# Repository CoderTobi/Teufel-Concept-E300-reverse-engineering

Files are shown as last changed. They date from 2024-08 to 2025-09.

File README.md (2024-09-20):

# Teufel Concept E300 Reverse Engineering
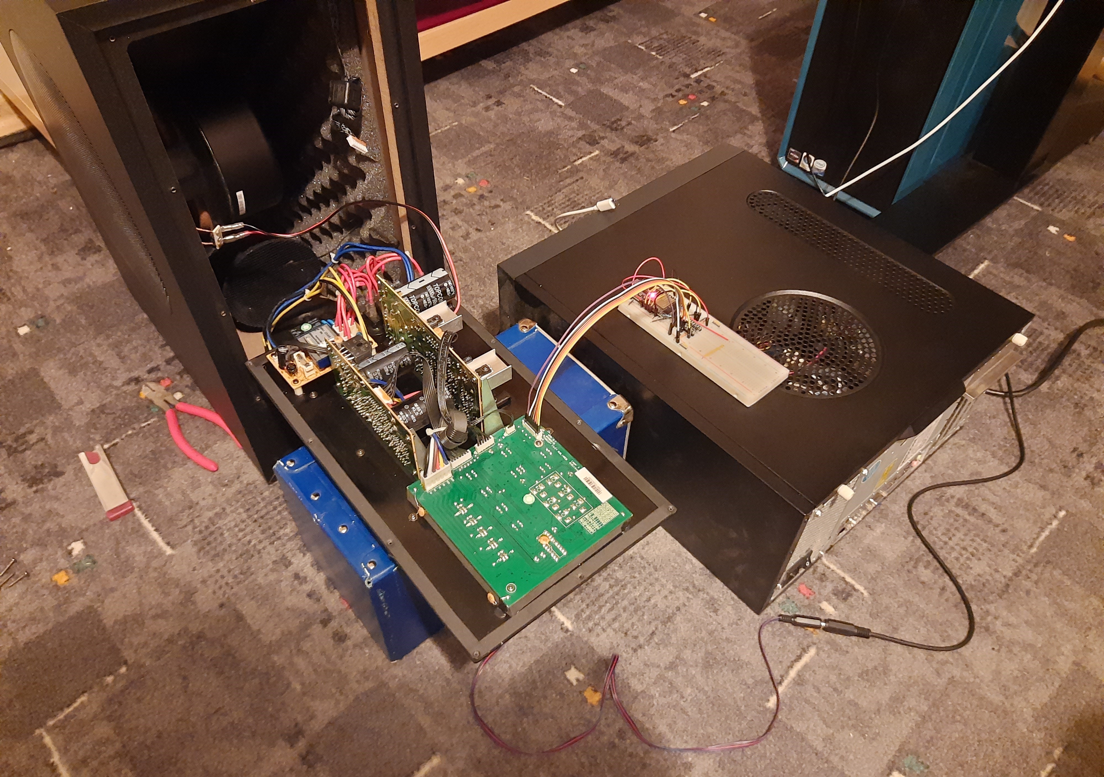
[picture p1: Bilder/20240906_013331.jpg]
Cover Bild

Dieses Repository enthält alle Dateien von meinem Reverse Engineering Projekt meines 5.1 Surround Sound Systems.
Beim System handelt es sich um einen Concept E3 der Marke Teufel.
Die Erkenntnisse aus diesem Projekt können jedoch sehr wahrscheinlich auf andere Systeme der Marke Teufel übertragen werden, solange sie aus einer ähnlichen Zeit stammen (ca. 2010).

## Warnung!
Das Testen und Sammeln von Informationen erforderte das Arbeiten am Subwoofer während er mit Netzspannung versorgt wurde. Sowohl die 230V Wechselspannung als auch die 50V Gleichspannung am Amplifier können potentiell tödlich sein. Wenn du nicht weist, was du tust und keine Erfahrung mit Elektronik hast, dann solltest du nicht mit solchen Spannungen arbeiten. Ich bin nicht verantwortlich solltest du dich bei einem ähnlichen Projekt oder dergleichen verletzen.

## For English speaking people
This repository contains all files for a hobby project of mine where I reverse engineered a 5.1 surround sound system manufactured by the German company Teufel. Since I am German and I don't think my system was sold outside of Germany I wrote all the documentation in German too. If my assumption was wrong or you're just interested in the project it's self, you can open an issue and request a translation... or just use a translator.

## Caution!
This project involved working on the subwoofer while it was connected to mains voltage and the components exposed. If you don't know what you are doing you should not do a project like this. I am not responsible if you hurt yourself or anything like that because you did know what you were doing.

## Hinweis
Dieses Projekt ist noch nicht abgeschlossen und unfertig.

## Motivation
Ich hab mich schon immer für Elektronik und deren Zusammenspiel mit Informatik interessiert. Dementsprechend hatte ich schon immer bei jedem Gerät das Interesse es zu zerlegen und herauszufinden wie es funktioniert.
Der Vorbesitzer meines Systems verkaufte mir damals das System, da es ihn störte jedes mal an den Subwoofer hin laufen zu müssen, um in aus dem Standby zu wecken. In Foren fand ich weitere Personen die es stört, dass das System jedes mal in den Standby zurückkehrt, wenn man die Stromversorgung unterbricht.
Da ich gefühlt jedes Gerät zu irgendeinem Zeitpunkt zerlege, war auch mein Subwoofer keine Ausnahme. Beim Zerlegen und Bewundern der Platine sprang mir eine Sache direkt ins Auge. Die Leitungen, die von der Gehäusefront mit dem Standbyknopf und den Lautstärkereglern zurück zum Mainboard führten, waren die Beschriftungen `SDA` und `SCL` aufgedruckt. Diese deuteten auf einen I2C Bus hin. Da Sowohl der Atmel Atmega328p (Arduino nano) als auch der ESP32 einen bzw. zwei I2C Busse haben entstand die Idee meinen Subwoofer Smart zu machen, sprich ihn nicht nur per WLAN wecken, sondern auch die Lautstärke einstellen zu können.
2024 entstand dann während meiner Semesterferien dieses Projekt aus der ursprünglichen Idee.

## Setup
Falls irgendjemand ebenfalls noch ein altes System der Firma Teufel hat und es auch in Home Assistant integrieren will habe ich ein paar Hilfestellungen dafür aufgeschrieben. Siehe: [Setup](Docs/Setup/README.md)

## Dokumentation meines Systems
Ich habe versucht alle meine Erkenntnisse über mein System in ein paar Markdown Dokumenten zusammenzufassen. Siehe: [Concept E3](Docs/Concept_E300/README.md)

## Reverse Engineering
Für die Leute, die sich vielleicht überlegen ein ähnliches Projekt durchzuführen oder einfach nur interessiert sind, wie ich dabei vorgegangen bin, habe ich ein bisschen Prosa verfasst. Siehe hier: [Reverse Engineering](Docs/Reverse_Engineering/README.md)

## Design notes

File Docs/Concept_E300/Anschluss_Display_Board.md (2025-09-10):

# Anschluss Display Board
Das Display Board auf welchem sich die Regler für die Lautstärke und den Bass, als auch der Knopf für den Standby befinden, ist über einen 7-Pin JST-HX Stecker mit dem Mainboard verbunden. Genau diesen Anschluss verwende ich, um meinen Subwoofer über HomeAssistant zu steuern.

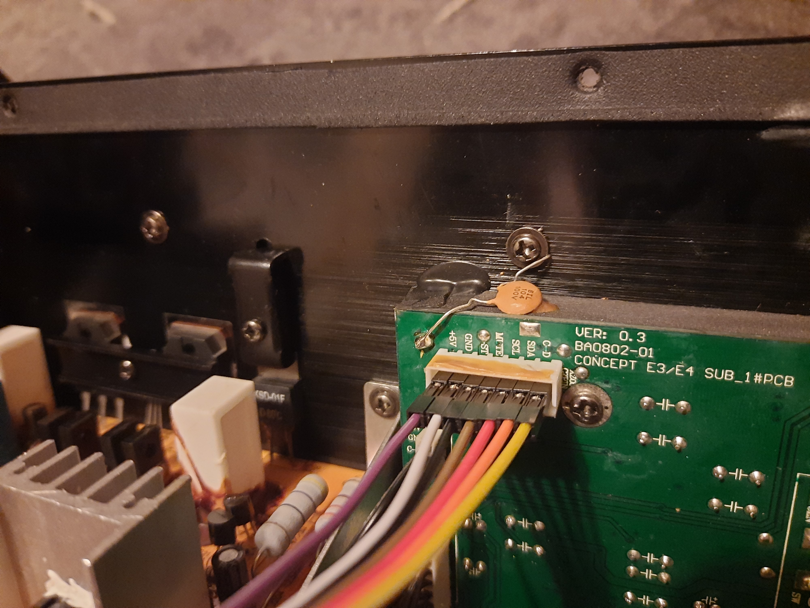
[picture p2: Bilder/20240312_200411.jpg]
Bild vom Anschluss am Mainboard


| Label | Bedeutung | high | low |
| --- | --- | --- | --- |
| +5V | | | |
| GND | | | |
| ST | Standby | Sleep | Work |
| MUTE/Control | | AMP an | AMP aus |
| SCL | | | |
| SDA | | | |
| C-D | Vielleicht Channel Disconnect | kein Audio | Audio erkannt |

## ST-Pin
Der ST-Pin ist für das Schalten des Standby Relais zuständig. Dieses unterbricht die Spannungsversorgung zum großen Trafo am Boden des Subwoofers. Wenn ST auf `HIGH` ist schaltet das Relais nicht durch. Wenn ST auf `LOW` ist schaltet das Relais durch und die beiden Amps werden über den großen Trafo mit Spannung versorgt.

Da ST am Standby Netzteil mit der Basis eines 2N5401 PNP Transistors verbunden ist, welcher dann wiederum über einen 2N5551 NPN Transistor das Relais schält, muss ST zuverlässig auf GND geschaltet werden, um das Relais zu steuern.
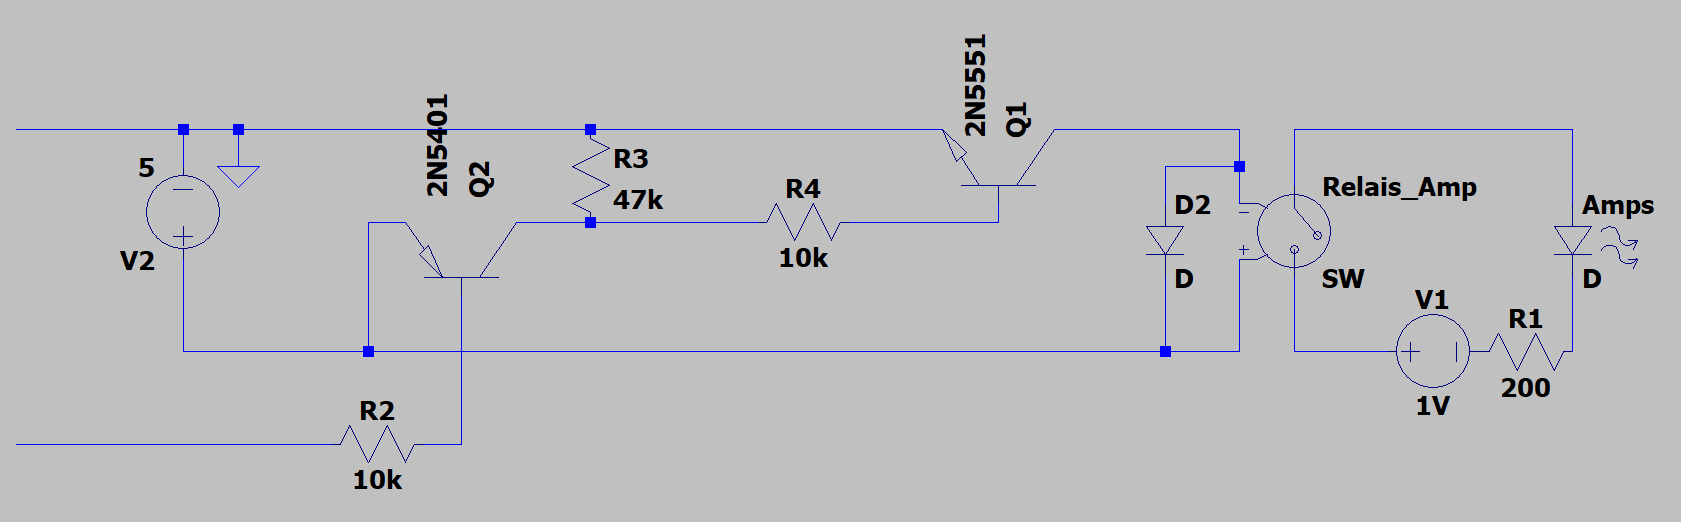
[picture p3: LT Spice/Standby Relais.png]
Schaltplan Standby Relais

Es reicht nicht ST direkt an einen ESP32 zu hängen und den GPIO-PIN auf `LOW` zu setzen. Dementsprechend funktionieren auch simple I2C Logic Level Shifter nicht, da diese nur das `LOW` Signal des Mikrocontrollers durchschalten und zusätzlich noch einen 10k Ohm Pull Up hinzufügt.

## MUTE / Control
Nach dem ST auf `LOW` geschaltet wurde, muss der MUTE Pin auf `HIGH` geschaltet werden. Das Display Board von Teufel wartet hier erst noch ca. 3 Sekunden bevor der Pin auf 5V geschaltet wird. Das Signal wird vom Mainboard glaub ich einfach an die beiden Amps durchgereicht. Beim Amp des Subwoofers wird MUTE als Control bezeichnet.

Wenn MUTE über einen GPIO Pin eines ESP32 auf 3,3V geschaltet wird, schält das Relais des Subwoofer Amps und entmutet in. Der AMP der Satelliten Lautsprecher ist dann jedoch unbrauchbar leise. Dies ist auch der Fall, wenn MUTE über einen 10k Ohm Pull Up auf 5V geschaltet wird. 
Dementsprechend funktionieren I2C Logic Level Shifter auch nicht, da diese nur einen 10K Ohm Pull Ip auf 5V verwenden.

MUTE wird nur korrekt als `HIGH` erkannt, wenn der Pin über einen 1k Ohm Pull Up oder direkt mit 5V verbunden wird. Siehe [Issue #3](https://github.com/CoderTobi/Teufel-Concept-E300-reverse-engineering/issues/3).

Mit meinem Multimeter habe ich versucht den Stromfluss auf MUTE bei `HIGH` zu messen, der Strom war jedoch zu gering für mein Messgerät.

## SCL und SDA
SCL und SDA werden für die Übertragung der Lautstärke über das I2C Protokoll verwendet. Siehe: [Protokoll](Protokoll.md)

## C-D
Ich weiß nicht genau wofür `C-D` steht. Aber es scheint vom Display Board mit wahrscheinlich 10k Ohm auf 5V hochgezogen zu werden. Wenn aber das Display Board getrennt wird, dann liegen an `C-D` entweder 4,8V oder 0V an, je nach dem, ob gerade Musik abgespielt wird. Es wird dabei jedoch nur Audio beachtet, dass über die beiden vorderen Lautsprecher (FR und FL) abgespielt werden soll.

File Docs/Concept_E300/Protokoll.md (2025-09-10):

# Protokoll
Das Display Board kommuniziert mit dem Restlichen System via I2C. 
Siehe für weitere Informationen auch [Aufbau](Aufbau.md) und [Anschluss Display Board](Anschluss_Display_Board.md).

## Aufbau eines Pakets
TODO

## Einschalten
Beim Einschalten wird zuerst `ST` auf `low` gesetzt.
Dann ca. 2,5 Sekunden gewartet.
Anschließend werden über ``I2C`` Daten ausgetauscht. (TODO)
Dann nach 0,35 Sekunden `MUTE`auf `high` gesetzt.

> [!CAUTION]
> `MUTE` darf erst auf `high` gesetzt werden, nachdem `ST` ca. 3 Sekunden auf `low` war.

> [!WARNING]
> Sollten die AMPs via I2C keine Informationen über die gewünschte Lautstärke erhalten, kann es zu unerwartetem Verhalten kommen.
> Auf Grund eines Wackelkontakts hatte ich beispielsweise schon den Fall, dass einer der Satelliten Lautsprecher extrem laut war.

## Ausschalten
Zuerst werden Daten via ``I2C`` ausgetauscht. (TODO)
Dann `MUTE` wird auf `low` gesetzt.
10 Mikro Sekunden später dann `ST` auf `high`.

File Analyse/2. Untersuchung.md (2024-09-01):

Herausfinden wofür der Pin CD ist:

- Pin hatte immer die gleiche Spannung von 4,4V (VCC)
- Spannung wurde vom Display Board geliefert
- Kein Unterschied ob auf High oder Low
- Verändert sich auch nich, wenn man eine Quelle anschließt oder was abspielt

Herausfinden wie sich der Sub verhält wenn der Bass-Regler auf max is und ich den Lautstärke Regler von min auf max dreh

- 2 neue Captures unter "Volume Slider"
- Verhält sich wie erwartet außer bei 100% Volume
- In der Excel Datei Diagramme erstellt
- Entscheidung: Abknicken beim Bass nicht implementieren, sondern einfach nur ein Schutz, dass die Dämpfung nicht negativ sein kann

Spannungen nachprüfen

- überall VCC (4,4V)
Stromstärke messen (Wichtig auf Pin Mute und ST weil die glaub direkt an das Relay gehen)
- Strom an ST und MUTE zu gering zum messen
- Strom gesamt max 30mA

CD in meiner Firmware implementieren

- Pin einfach immer auf HIGH gesetzt

Vielleicht einen Test mit meinem ESP machen

- Anpassungen an Firmware bezüglich Volume bei 100% und Bass Veränderungen

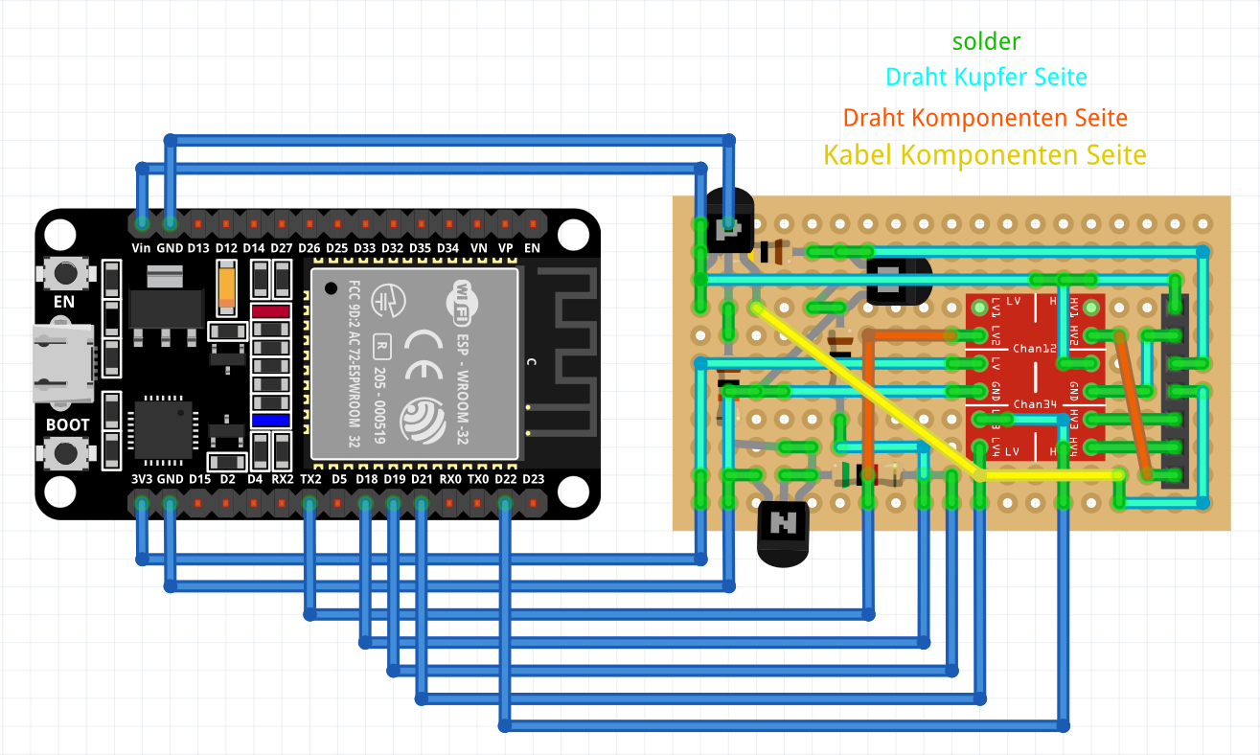
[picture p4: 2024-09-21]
Fritzing/Perfboard.png

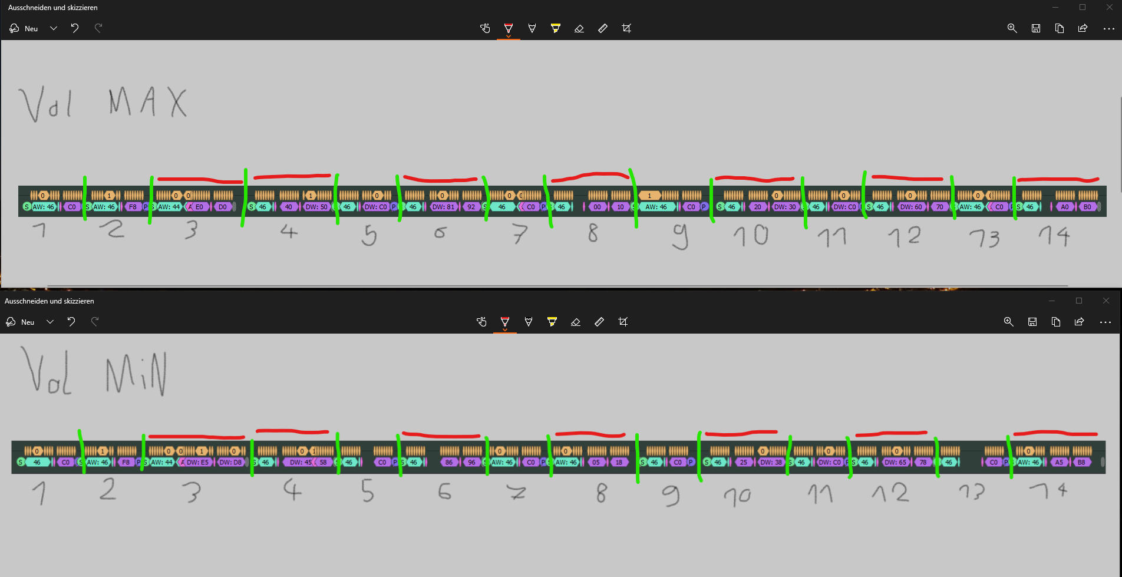
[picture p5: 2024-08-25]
Analyse/Paket Analyse Volume.png

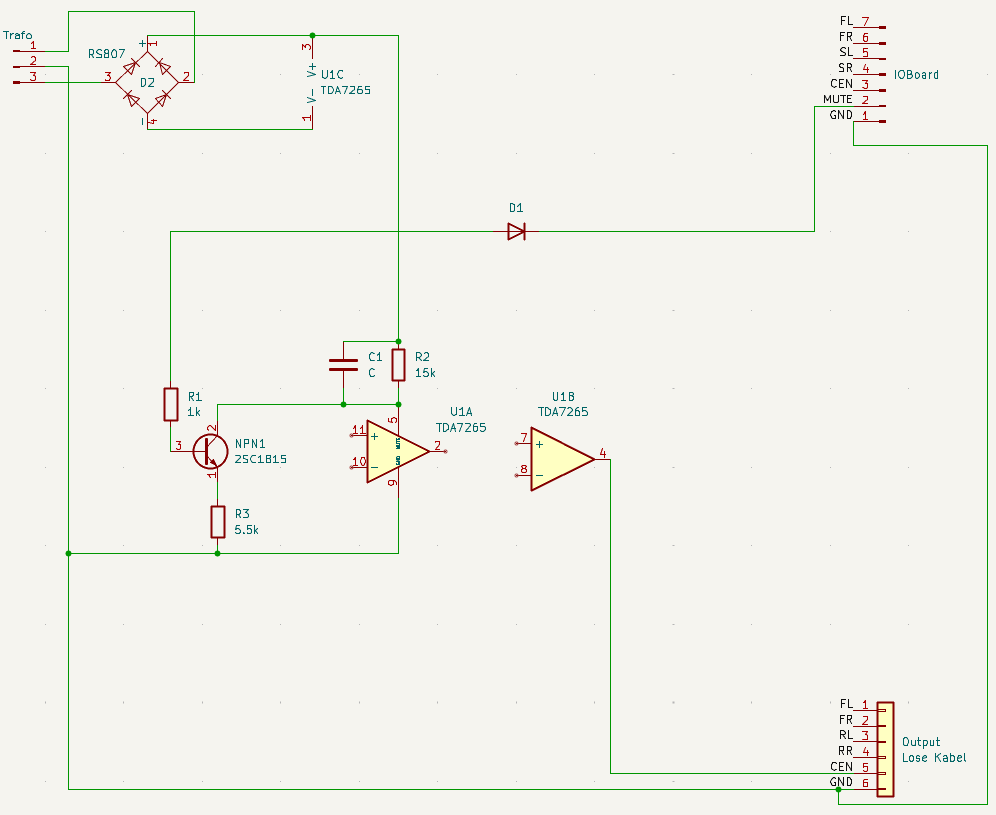
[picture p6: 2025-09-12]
KiCad/SatelliteAMP.png

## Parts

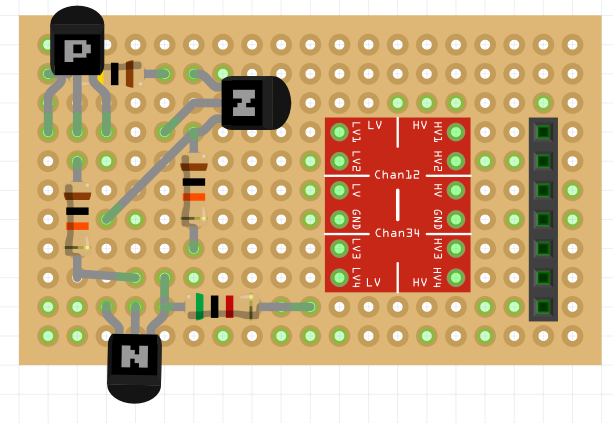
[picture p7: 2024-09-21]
Fritzing/Perfboard-Components_only.png

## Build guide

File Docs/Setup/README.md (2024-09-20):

# Setup
In diesem Bereich ist beschrieben, wie ein System mit einem ESP32 Microcontroller um smarte Funktionen ergänzt werden kann

## Unterstützte Systeme
- Teufel Concept E300 5.1 (CE300SW)
### Wahrscheinlich unterstützt
- Teufel Concept E100 5.1 (CE100SW)
- Teufel Concept E200 5.1 (CE200SW) (glaub ich gleich wie CE300SW)
- Teufel Concept E400 5.1 (CE400SW)
### Potenziell unterstützt aber Anpassungen nötig
- Teufel Concept E Magnum (CEM500SW)
- Teufel Concept F 5.1 (CF550/6SW)
- Teufel Concept E150 (US2108/6SW)
- Teufel Concept S
- Tendenziell alte Teufel Systeme von 2010

## Voraussetzungen
### Fähigkeiten
- Löten 
- Sicherer Umgang mit Leistungselektronik (230V)
### Infrastruktur
- Home Assistant
- MQTT Broker (bsp. Mosquito)
### Werkzeug
- Lötstation bzw. Lötkolben

  **Falls Anpassungen nötig sind:**
- Breadboard und Jumper-Wire
- Logic Analyzer

## Installation und Einrichtung
- Elektronik: [Elektronik](Elektronik.md)
- Home Assistant: [Home Assistant](HA.md)

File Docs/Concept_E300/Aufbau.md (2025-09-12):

# Aufbau Subwoofer
Der Subwoofer hat vier Platinen an seiner Rückseite. 

## 5V Standby Netzteil und Relay
Die kleinste Platine ist ein 5V Netzteil welches das Frontpanel bzw. Display Board mit Strom versorgt. 
Das Netzteil ist dauerhaft aktiv, solange der Hauptschalter aktiviert ist.
Es hat außerdem ein Relay, welches den großen Transformator mit 230V Wechselspannung versorgt, sobald das Frontpanel den Standby Pin `ST` auf `high` setzt.

## Transformator
Im unteren Teil des Subwoofer gibt es einen sehr großen Trafo, welcher die 230V 50Hz Wechselspannung in zwei andere Wechselspannungen transformiert.
Eine Ausgang geht an den Subwoofer AMP, der andere an den Satelliten AMP.
### Anschlüsse
#### Standby Netzteil
- 2 x dicke Rote Kabel 230V 50Hz
#### Subwoofer AMP
- Dickes Blaues Kabel
- Dickes Schwarzes Kabel
- Dickes Blaues Kabel
#### Satelliten AMP
- Dickes Gelbes Kabel
- Dickes Schwarzes Kabel
- Dickes Gelbes Kabel

# Display Board bzw. Frontpanel
Teufel bezeichnet diese Platine als Display Board, obwohl es keinerlei Displays besitzt.
Daher bezeichne ich es auch gerne als Frontpanel.
Es beherbergt einen Pushbutton (Standby Knopf) und zwei Potentiometer (Bass und Volume Regler).
Außerdem befindet sich dort ein IC und ein 7-Pin JST-HX Anschluss, über welchen es mit dem IO Board verbunden ist.
Siehe auch: [Anschluss Display Board](Anschluss_Display_Board.md)

## IO Board
Am IO Board befinden sich die ganzen äußeren Anschlüsse des Subwoofer.
Dort befindet sich auch der Anschluss des Frontpanels bzw. Display Boards.
Manchmal bezeichne ich es auf Grund seiner Position auch als Mainboard.
Das Board scheint nicht wirklich viel Logik zu beherbergen, obwohl es einen IC hat.
Das `MUTE` Signal vom Frontpanel wird hier an die beiden AMPs durchgereicht.
Das `ST` Signal vom Frontpanel wird ebenfalls einfach an das Relay des Netzteils durchgereicht.
### Beschriftungen:
- VER: 0.3
- BA0802-01
- CONCEPT E3/E4 SUB_1#PCB
- Layer 2 SIZE: 131mm...
### Anschlüsse:
#### Frontpanel (JST-HX)
- +5V
- GND
- C-ST
- MUTE
- SCL
- SDA
- C-D
#### Standby Netzteil
- C-ST
- GND
- +5V
#### Subwoofer AMP
- SW_SI
- GND
- +15V
- GND
- -15V
- MUTE
#### Satelliten AMP
- FL
- FR
- SL
- SR
- CEN
- MUTE
- GND
#### Satelliten AMP Output
- FL
- FR
- RL
- RR
- CEN
- GND

## Subwoofer AMP
Das `MUTE` Signal des Frontpanels wird hier genutzt, um ein weiteres Relay zu schalten.
Wenn `MUTE` auf `high` wechselt schält das Relay durch und der Subwoofer macht Töne.
Bei `low` ist er stumm geschaltet.
Da er zwei große 10.000 Micro Farad 50V Kondensatoren besitzt wird er erst nach einer gewissen Zeit vom Frontpanel unmuted.
Ansonsten bekommt das Board seinen Strom vom Trafo und sein Audio Signal vom IO Board.
### Beschriftungen:
- VER: 0.3
- BA0801-04
- CONCEPT E3/E4/EXTREME
- SIZE: 150mmx86mm
### Anschlüsse:
#### IO Board
- SIGNAL
- GND
- +15V
- GND
- -15V
- CONTROL

## Satelliten AMP
Dieser AMP ist ebenfalls stumm, bis `MUTE` vom Frontpanel auf `high` gesetzt wird.
Er besitzt jedoch kein eigenes Relay. 
Jedoch haben seine Kondensatoren auch nur eine Spannungsfestigkeit von 35V und nicht 50V.
### Beschriftungen:
- VER: 2.5
- MAGNUM BASIC | SUB_3#PCB
- 2009/3/3

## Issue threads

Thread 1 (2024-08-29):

Random Pause beim Senden von Daten via I2C

CoderTobi, 2024-08-29:
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
Aus irgendwelchen Gründen pausiert der ESP random beim Senden...

CoderTobi, 2024-08-29:
Problem lag am Arduino Uno. Da waren noch prints im Call Back weshalb der Arduino überfordert war und dann die Daten nicht mehr annehmen konnte.
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

Closed 2024-08-29.

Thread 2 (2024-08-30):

Slider und Schalter in HA springen hin und her nach dem man viel hintereinander gemacht hat.

CoderTobi, 2024-08-30:
Es dauert glaube ich sehr lange bis der neue Status an HA zurück gemeldet wird. Dadurch kann es sein, dass man den Laustärke Regler hin und her schiebt und er sich anschließend noch mal wieder zurück bewegt und dann die letzten Schritte quasi wiedergibt.
Die Doku von ArduinoHA sagt, dass es ok ist `mqtt.loop();` alle 15ms oder so aufzurufen. Aktuell kanns auch mal sein, dass dazwischen ein Delay von mehreren Sekunden liegt. Das schlecht.
TODO: `delay()` Funktion ersetzen, damit `mqtt.loop();` trotzdem aufgerufen wird.

Closed 2024-08-31.

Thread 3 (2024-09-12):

Satelieten Lautsprecher unbrauchbar leise

CoderTobi, 2024-09-12:
- 3,3V an MUTE sind nicht genug.
- Amp von den kleinen Lautsprechern verwendet Transistoren, keine Relais.
- 5V mit 10k Vorwiderstand waren auch nicht besser. 5V mit 1k Vorwiderstand haben funktioniert.
TODO: Board anpassen und Bipolar NPN Transistor einbauen zum MUTE schalten nach Vorbild von ST.

CoderTobi, 2024-09-19:
NPN funktioniert nicht, da NPN hinter die Last muss aber bei MUTE dann vor der Last hängt. Somit ist dann IBE abhängig von der Last und zu klein.
TODO: PNP Auftreiben, weil da fließt der Strom quasi aus der Basis raus und nicht rein. Somit kann der vor die Last gehängt werden. Rausfinden welchen Typ ich brauch.

CoderTobi, 2024-09-20:
Keine PNP Transistore genfunden im Haus, welche auf Amazon bestellt.
Simpler I2C Logic Level Shifter hat wenig unerwartet auch nicht funktioniert, da er ein `HIGH` Signal erzeugt, in dem er den Ausgang über einen 10k Ohm Widerstand auf 5V legt, was nicht funktioniert.
**Test durchgeführt:**
- Kann kein Unterschied hören, zwischen `MUTE` direkt auf 5V oder über 1k Widerstand.
- Strom gemessen, aber war immer bei 0mA. Messgerät getestet, das funktioniert.

CoderTobi, 2024-09-21:
Weitere Tests mit NPN Trabsistor gemacht und 1k Ohm an der Basis. Transistor schält trotzdem nicht.
Test mit PNP (BC557B) war erfolgreich. Ich glaub ich kann den Transistor aber nicht direkt über den ESP schalten, daher noch ein NPN davor. Tests gemacht, ob ein Unterschied hörbar ist zwischen meiner PNP-NPN-Schaltung und dem original Display Board, aber kein Unterschied hörbar.
Schaltplan angepasst:
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
Platine angepasst:
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

CoderTobi, 2025-09-10:
Idee für neue Werte:
- MUTE PNP Vorwiederstand von 10k auf 4,7k reduzieren
- MUTE NPN Vorwiederstand von 5k auf 1k reduzieren
- Vielleicht direkt nach MUTE NPN 100k pull up
- Vielleicht ST NPN Vorwiederstand von 10k auf 5k reduzieren

Closed 2024-09-21.

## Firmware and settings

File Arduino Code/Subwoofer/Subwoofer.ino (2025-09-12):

#include <WiFi.h>
#include <ESPmDNS.h>
#include <ArduinoOTA.h>
#include <ArduinoHA.h>
#include <Wire.h>
#include "secrets.hpp"

// Pin Config - ESP-WROOM-32 Dev Kit
const uint8_t CD_PIN = 17;
const uint8_t SDA_PIN = 21;
const uint8_t SCL_PIN = 22;
const uint8_t MUTE_PIN = 19;
const uint8_t ST_PIN = 18;

// General Config
const int playingChangedDelay_off = 2000; // Wie lange(ms) das Signal auf CD HIGH bleiben muss, bis der Status geändert wird
const int playingChangedDelay_on = 100; // Wie lange(ms) das Signal auf CD LOW bleiben muss, bis der Status geändert wird

// Globale Variablen
uint8_t targetVol = 0; // Wert zwischen 0 und 100
uint8_t targetBass = 0; // Wert zwischen 0 und 100
uint8_t currentVol = 0; // Wert zwischen 0 und 100
uint8_t currentBass = 0; // Wert zwischen 0 und 100
bool targetPower = false; // true=on und false=standby
bool currentPower = false; // true=on und false=standby
bool playing = false;
unsigned long playingChanged = 0;

WiFiClient client;
HADevice device("Subwoofer");
HAMqtt mqtt(client, device);

// Meine Devices
// device types need to be constructed after HAMqtt class.
HANumber numberAll("VolAll");
HANumber numberBass("VolBass");
HASwitch switchPower("Power");
HABinarySensor sensorPlaying("Playing");

// ===================================== Other =================================

// Funktioniert nicht, da er nicht extra den Server fragt, sondern den lokalen cache verwendet
/*
void fetchVolFromHA()
{
  HANumeric all = numberAll.getCurrentState();
  targetVol = all.toUInt8();
  Serial.print("MQTT_fetchVol: ");
  Serial.println(targetVol);
  HANumeric bass = numberBass.getCurrentState();
  targetVol = bass.toUInt8();
  Serial.print("MQTT_fetchBass: ");
  Serial.println(targetBass);
}
*/

// Delay Ersatz, der trotzdem MQTT pflegt
void myDelay(int ms)
{
  unsigned long startMillis = millis();
  while((millis() - startMillis) < ms)
  {
    mqtt.loop();
    checkForAudio();
  }
}

void checkForAudio()
{
  if( playing != digitalRead(CD_PIN))
  {
    playingChanged = millis();
  }

  if(playing)
  {
    if ((millis() - playingChanged) > playingChangedDelay_off)
    {
      playingChanged = millis();
      playing = !playing;
      sensorPlaying.setState(playing);
    }
  }
  else
  {
    if ((millis() - playingChanged) > playingChangedDelay_on)
    {
      playingChanged = millis();
      playing = !playing;
      sensorPlaying.setState(playing);
    }
  }
}

// ===================== Call Backs ========================

void onSwitchCommand(bool state, HASwitch* sender)
{
  Serial.print("MQTT_Standby: ");
  Serial.println(state);

  targetPower = state;

  sender->setState(state); // report state back to the Home Assistant
}

void onVolAllChange(HANumeric number, HANumber* sender)
{
  if (!number.isSet()) {
      // the reset command was send by Home Assistant
  } else {
    // you can do whatever you want with the number as follows:
    uint8_t value = number.toUInt8();
    Serial.print("MQTT_Vol: ");
    Serial.println(value);
    targetVol = value;
  }

  sender->setState(number); // report the selected option back to the HA panel
}

void onVolBassChange(HANumeric number, HANumber* sender)
{
  if (!number.isSet()) {
      // the reset command was send by Home Assistant
  } else {
    // you can do whatever you want with the number as follows:
    uint8_t value = number.toUInt8();
    Serial.print("MQTT_Bass: ");
    Serial.println(value);
    targetBass = value;
  }

  sender->setState(number); // report the selected option back to the HA panel
}

// -------------------- OTA -------------------
void onOTAStart()
{
  String type;
  if (ArduinoOTA.getCommand() == U_FLASH) {
    type = "sketch";
  } else {  // U_SPIFFS
    type = "filesystem";
  }

  // NOTE: if updating SPIFFS this would be the place to unmount SPIFFS using SPIFFS.end()
  Serial.println("Start updating " + type);
}


void onOTAEnd() 
{
  Serial.println("\nOTA Done");
}

void onOTAProgress(unsigned int progress, unsigned int total) 
{
  Serial.printf("Progress: %u%%\r", (progress / (total / 100)));
}

void onOTAError(ota_error_t error) 
{
  Serial.printf("Error[%u]: ", error);
  if (error == OTA_AUTH_ERROR) {
    Serial.println("Auth Failed");
  } else if (error == OTA_BEGIN_ERROR) {
    Serial.println("Begin Failed");
  } else if (error == OTA_CONNECT_ERROR) {
    Serial.println("Connect Failed");
  } else if (error == OTA_RECEIVE_ERROR) {
    Serial.println("Receive Failed");
  } else if (error == OTA_END_ERROR) {
    Serial.println("End Failed");
  }
}
// ===================================== I2C ===================================

// ------------------------- helper --------------------

// Nimmt eine Binärzahl und wandelt sie in zwei BCD Ziffern um
uint8_t binToBCD(uint8_t bin)
{
  // Beispiel: 36
  uint8_t bcd2 = bin % 10;    // 36 => 6
  uint8_t bcd1 = bin - bcd2;  // 36 => 30
  bcd1 = bcd1 / 10;   // 30 => 3
  bcd1 = bcd1 << 4;   // 0000 0011 => 0011 0000
  return bcd1 | bcd2; // 0011 0110
}

// ------------------------------------------------------

void i2c_write_sep()
{
  Wire.beginTransmission(0x46);
  Wire.write(0xC0);
  Wire.endTransmission(true);
}

void i2c_write_power(bool on)
{
  Wire.beginTransmission(0x46);
  if(on)
  {
    Wire.write(0xF8);
  }
  else
  {
    Wire.write(0xF9);
  }
  Wire.endTransmission(true);
}

// Wird von sendUpdate() und turnOn() aufgerufen
// schreibt nur die Payload
// volReduction und bassReduction sind beides Binärzahlen
void i2c_write_volume(uint8_t volReduction, uint8_t bassReduction)
{
  Serial.print("DEBUG volred: ");
  Serial.print(volReduction);
  Serial.print(" bassred: ");
  Serial.println(bassReduction);

  uint8_t volBCD = binToBCD(volReduction);
  uint8_t bassBCD = binToBCD(bassReduction);
  
  i2c_write_data(0x44, 0xED, volBCD);  // Volume All

  i2c_write_data(0x46, 0x45, volBCD);  // Volume CH1
  i2c_write_sep();
  i2c_write_data(0x46, 0x89, bassBCD); // Volume CH2 - Sub
  i2c_write_sep();
  i2c_write_data(0x46, 0x01, volBCD);  // Volume CH3
  i2c_write_sep();
  i2c_write_data(0x46, 0x23, volBCD);  // Volume CH4
  i2c_write_sep();
  i2c_write_data(0x46, 0x67, volBCD);  // Volume CH5
  i2c_write_sep();
  i2c_write_data(0x46, 0xAB, volBCD);  // Volume CH6
}

// Wird von i2c_write_volume() mehrfach aufgerufen
// Schreibt 2 Bytes wobei bei jedem Byte die ersten 4 bit die Adresse des Register sind und die restlichen 4 die BCD Ziffer 
void i2c_write_data(uint8_t address, uint8_t reg, uint8_t bcdNumbers)
{
  uint8_t reg1 = reg & 0xf0;
  uint8_t reg2 = reg & 0x0f;

  uint8_t bcd1 = bcdNumbers & 0xf0;
  uint8_t bcd2 = bcdNumbers & 0x0f;

  uint8_t data1 = bcd1;
  data1 = data1 >> 4;
  data1 = data1 | reg1;

  uint8_t data2 = reg2;
  data2 = data2 << 4;
  data2 = data2 | bcd2;
  
  Wire.beginTransmission(address);
  Wire.write(data1);
  Wire.write(data2);
  Wire.endTransmission(true);
}

// ==================================== Actions =================================

void turnOn()
{  
  // Aus Standby wecken
  // ST muss GND gezogen werden, damit das Relais schaltet
  // Daher Pin auf high, damit der NPN Transistor durchschält und ST auf LOW zieht
  // Wichtig! Transistor nicht vergessen
  digitalWrite(ST_PIN, HIGH);

  myDelay(2491);

  i2c_write_power(true);
  i2c_write_sep();
  i2c_write_power(true);
  i2c_write_volume(76, 78); // Dämpfung manuell auf was sehr niedriges setzen
  
  sendUpdate(); // Tatsächliche Lautstärke(Dämpfung) senden

  myDelay(350);

  digitalWrite(MUTE_PIN, HIGH); // MUTE deaktivieren(HIGH)

  myDelay(3);

  sendUpdate();
}

void turnOff()
{
  i2c_write_power(false);
  digitalWrite(ST_PIN, LOW); // LOW -> NPN zieht nicht mehr auf GND -> Pull Up zieht auf 5V
  digitalWrite(MUTE_PIN, LOW);
}

void sendUpdate()
{
  currentBass=targetBass;
  currentVol=targetVol;

  i2c_write_sep();
  i2c_write_power(true);

  uint8_t volReduction = 0;
  uint8_t bassReduction = 0;
  int bassReductionInt = 0;

  volReduction = map(currentVol, 0, 100, 58, 0);

  bassReductionInt = volReduction + map(currentBass, 0, 100, 8, -4);
  if(bassReductionInt < 0)
  {
    bassReduction = 0;
  }
  else{
    bassReduction = (uint8_t) bassReductionInt;
  }

  // Vorsicht uint, somit gibt negative = Unfall
  i2c_write_volume(volReduction, bassReduction);
}

// ===================================== Setup ===================================

void setup() 
{
  // Serial Setup
  Serial.begin(115200);
  Serial.print("Wifi"); 

  // PIN Mode Setup
  pinMode(ST_PIN, OUTPUT); 
  pinMode(MUTE_PIN, OUTPUT);
  pinMode(CD_PIN, INPUT);
  digitalWrite(ST_PIN, LOW); // LOW -> NPN sperrt -> Pull Up zieht auf 5V -> Relais schält nicht
  digitalWrite(MUTE_PIN, LOW);

  // I2C Setup
  Wire.begin(SDA_PIN, SCL_PIN);
  Wire.setClock(50000); // Original arbeitet bei 64kHz
  //Wire.setTimeout(0); // NUR ZUM TESTEN

  // Wifi verbinden
  WiFi.begin(WIFI_SSID, WIFI_PW);
  while (WiFi.status() != WL_CONNECTED) {
    Serial.print("."); 
    myDelay(500); // waiting for the connection
  }
  Serial.println("connected");

  // Device Setup
  device.setName("Teufel-Soundsystem");

  // Device Types Setup
  switchPower.onCommand(onSwitchCommand);
  switchPower.setIcon("mdi:power-standby");
  switchPower.setName("Power");
  numberAll.setName("Volume Allgemein");
  numberAll.setIcon("mdi:speaker-multiple");
  numberAll.onCommand(onVolAllChange);
  numberBass.setName("Volume Bass");
  numberBass.setIcon("mdi:volume-vibrate");
  numberBass.onCommand(onVolBassChange);
  sensorPlaying.setName("Playing");
  sensorPlaying.setIcon("mdi:play-circle");
  sensorPlaying.setDeviceClass("sound");

  // LWT aktivieren
  device.enableSharedAvailability();
  device.enableLastWill();

  // MDNS
  MDNS.begin("Subwoofer");

  // OTA
  ArduinoOTA.setHostname("Subwoofer");
  ArduinoOTA.setPassword(OTA_PW);
  ArduinoOTA.onStart(onOTAStart);
  ArduinoOTA.onEnd(onOTAEnd);
  ArduinoOTA.onProgress(onOTAProgress);
  ArduinoOTA.onError(onOTAError);
  ArduinoOTA.begin();

  // CD Check Setup
  playingChanged = millis();

  // MQTT broker connection (muss ans Ende von Setup)
  mqtt.begin(MQTT_HOST, MQTT_USER, MQTT_PW);
}

// ===================================== Loop ===================================

void loop() {
  mqtt.loop();
  checkForAudio();

  if(targetPower != currentPower)
  {

    currentPower = targetPower;

    if (currentPower)
    {
      //fetchVolFromHA();
      turnOn();
    }
    else 
    {
      turnOff();
    }

    myDelay(1000); // Anti Spam
  }

  if( (currentPower == true) && ((currentBass != targetBass) || (currentVol != targetVol)) )
  {
    sendUpdate();

    myDelay(100); // Anti Spam
  }

  // Wenn wir im Standby sind
  if(currentPower == false)
  {
    // OTA Updates durchführen
    ArduinoOTA.handle();
  }
}

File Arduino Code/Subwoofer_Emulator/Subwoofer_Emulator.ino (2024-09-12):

#include <Wire.h>

void setup() {
  //Wire.begin(0x46); // Start I2C Bus als Slave mit der Adresse 0x46
  Wire.begin(0x44); // Start I2C Bus als Slave mit der Adresse 0x44
  Wire.setClock(50000); // Original arbeitet bei 64kHz
  Wire.onReceive(receiveEvent); // register event
  Serial.begin(115200); // Starten der seriellen Kommunikation
}

void loop() {
  //delay(100);
}

// Funktion, die aufgerufen wird, wenn Daten empfangen werden
// Darf nicht zu viele Prints enthalten Siehe Issue #1 auf GH
void receiveEvent(int bytes) {
  while(Wire.available()) {
    uint8_t data = Wire.read(); // Empfangen von einem Byte als Zeichen
    //Serial.print("HEX: ");
    Serial.println(data, HEX); // Ausgabe des Wertes in HEX
    //Serial.print("BIN: ");
    //Serial.println(data, BIN); // Ausgabe des Wertes in BIN
    //Serial.print("DEC: ");
    //Serial.println(data, DEC); // Ausgabe des Wertes in DEC
  }
}

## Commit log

2024-08-25 Repo angelegt Datei "secrets.hpp" wird nicht mir hochgeladen!
    [Analyse.xlsx]
2024-08-25 Grundlage fertig - Clean Ups - Const für Pins - Slider und Einschalter hinzugefügt - Call Backs für alle 3 erstellt und getestet
2024-08-25 Digramm hinzugefügt
    [Analyse.xlsx]
2024-08-25 Pin Mode Setup added
2024-08-28 Analyse Diagramm hinzugefügt
    [Analyse.xlsx]
2024-08-28 Erkenntniss BCD Codierung Die Lautstärke wird nicht wie erwartet als 8 Bit Binärzahl übertragen, sondern als 2 BCD codierte Ziffern mit je 4 Bit
    [Analyse.xlsx]
2024-08-29 I2C Vorbereitung - PinMode Setup vor WLAN - I2C Setup hinzugefügt - I2C Methoden angelegt - I2C noch nicht getestet - Unsicher ob ESP32 64kHz kann
    [Analyse.xlsx]
2024-08-30 Subwoofer Emulator hinzugefügt - Test Sketch für einen Arduino UNO um ACK Nachrichten für die Addresse 0x46 zu generieren
2024-08-30 Basic ArduinoHA Implementierung fertig - Grundsätzlich fertig - Feinschliff noch nötig - Siehe Issue #2 - Weitere Tests durchführen ggf. weiteren ESP32 mit 2 I2C für 0x44 und 0x46 verwenden
    [Subwoofer.ino]
2024-08-31 Bug Fixes - Fixes #2 durch die Funktion `myDelay)=` - Versuch Problem zu beheben, dass der Subwoofer immer mit Volume 0 staretet. Am besten mit Automation und Helfer in HA lösen - Kann den Subwoofer 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
    [Subwoofer.ino]
2024-09-01 Untersuchung 2 - Weitere Capture gemacht - Verhalten von Bass bei Max Vol angepasst - Protokoll als MD Datei hinzugefügt - CD Pin einfach immer auf High - Weitere Diagramme hinzugefügt
    [Analyse.xlsx]
2024-09-02 1 Test an Hardware - Lief schlecht - Captures hinzugefügt - Mainboard scheint etwas über I2C zu verlangen - Unerwartet viel Aktivität auf CD Leitung
2024-09-03 Weitere Captures Hinweis: Mein Analyzer cached glaub das zuletzt empfangene Signal. Daher kann ein HIGH oder ein LOW auch einfach ein fliegender Pin sein.
2024-09-05 Board Wechsel vom LOLIN Lite zum ESP32 dev module
2024-09-07 OTA und mDNS Support - kleinere Änderungen - OTA - mDNS - Serial Baudrate auf 115200
2024-09-08 Perfboard designed
    [ESP control board - 1.fzz, ESP control board - 2.fzz, ESP control board.fzz]
2024-09-12 Pin config angepasst auf Perfboard
2024-09-12 Ursache gefunden - 3,3V nicht genug für MUTE - 5V mit 10k Vorwiderstand auch nicht genug - 5V mit 1k Vorwiderstand funktioniert - Perfboard ändern und weiteren NPN einfügen
    [ESP control board - 3.fzz]
2024-09-20 Bild hinzugefügt und MD korrigiert
2024-09-21 Schaltung und Platine um Elektronik für MUTE ergänzt. Fixes #3
    [ESP control board - 3.fzz]
2024-09-21 Platine und Schaltplan als Bilder exportiert
2024-09-21 Perfboard mit nur Komponenten exportiert und kleine Korrektur
    [ESP control board - 3.fzz]
2025-09-12 gitignore update for KiCad
2025-09-12 Anschlüsse und Beschriftungen der Platinen hinzugefügt
2025-09-12 SatelliteAMP Mute in KiCad aufgezeichnet
    [SatelliteAMP.kicad_pcb, SatelliteAMP.kicad_sch]
2025-09-12 Fix: MAC wurde nie richtig aus dem Wifi Modul extrahiert
    [Subwoofer.ino]
2025-09-12 ID von der MAC auf "Subwoofer" geändert. Hatte Probleme mit der Erkennung in Home Assistent. Außerdem wird so ein späterer HW-Wechsel einfacher, falls ich den ESP wieder frittiere.
    [Subwoofer.ino]
2025-09-13 #3 Schaltplan auf neue Werte aktualisiert und labels verwendet.
    [ESP control board - 1.fzz, ESP control board - 2.fzz, ESP control board - 3.fzz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]
